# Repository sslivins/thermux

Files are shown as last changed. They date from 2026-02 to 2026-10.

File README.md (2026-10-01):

# Thermux

A multi-sensor temperature monitoring system for ESP32-POE boards with Home Assistant integration via MQTT auto-discovery. **Supports 20 DS18B20 sensors on a single 1-Wire bus by default, configurable up to 100** (`CONFIG_MAX_SENSORS`) - perfect for monitoring multiple zones, equipment, or environments from one device.

## Features

- **Up to 100 DS18B20 Sensors** - Monitor multiple temperature points from a single device on one 1-Wire bus (20 by default; raise `CONFIG_MAX_SENSORS` in menuconfig, max 100)
- **Optimized Parallel Reads** - Uses 1-Wire skip ROM command to read all sensors simultaneously (~1050ms for 20 sensors in 12-bit mode, ~450ms in 9-bit)
- **Home Assistant Integration** - MQTT auto-discovery for seamless integration
- **Modbus TCP** - Optional read-only Modbus TCP server so PLCs and heat pump controllers can read temperatures directly (see [Modbus TCP](#modbus-tcp))
- **BACnet/IP** - Optional read-only BACnet/IP server for building-automation systems (see [BACnet/IP](#bacnetip))
- **Web Interface** - Configuration and monitoring via built-in web server
- **Sensor Identification** - Change detection highlighting helps identify which physical sensor is which
- **Custom Sensor Names** - Assign friendly names to sensors via web UI (persisted in NVS)
- **OTA Updates** - Over-the-air firmware updates from GitHub releases or manual upload with progress display, including a native Home Assistant firmware **update entity** with an Install button and progress bar
- **Ethernet & WiFi** - Primary Ethernet with WiFi fallback
- **mDNS** - Access via `thermux.local` (auto-increments on collision: thermux-2.local, etc.)
- **Service Discovery** - Discoverable via `_thermux._tcp` and `_http._tcp` services
- **Web-based Logs** - View system logs without serial connection (16KB circular buffer)
- **Bus Error Tracking** - Monitor 1-Wire CRC error rates per sensor and globally via web UI and Home Assistant
- **Runtime Log Level Control** - Change log verbosity via web UI without reflashing
- **Session-based Authentication** - Optional password protection with login page
- **API Key Authentication** - Stateless API access for scripts and automation

## Hardware Requirements

- **Board**: [Olimex ESP32-POE-ISO](https://www.olimex.com/Products/IoT/ESP32/ESP32-POE-ISO/) (or compatible ESP32-POE board)
- **Sensors**: DS18B20 1-Wire temperature sensors
- **Connection**: Sensors connected to GPIO4 (configurable in menuconfig)
- **PCB** (optional): Custom breakout board - see [hardware/](hardware/) for KiCad files and BOM
- **Enclosure** (optional): 3D printable case - see [enclosure/](enclosure/) for print files

### Wiring

| DS18B20 Pin | ESP32-POE |
|---|---|
| VCC (Red) | 3.3V |
| GND (Black) | GND |
| DATA (Yellow) | GPIO4 |

> **Note**: A 4.7kΩ pull-up resistor is required between DATA and VCC. For 10+ sensors, use 2.2kΩ or 1.5kΩ to ensure reliable bus communication (the ESP32's internal pull-up is too weak for 1-Wire).

## Installation

### Pre-built Firmware (Recommended)

Download the latest firmware from [GitHub Releases](https://github.com/sslivins/thermux/releases/latest) and follow the [FLASHING.md](FLASHING.md) guide.

**For brand new ESP32-POE devices**, you'll need all three files:
- `bootloader.bin`
- `partition-table.bin`
- `thermux.bin`

**For OTA updates** on devices already running Thermux, use the web interface at `http://thermux.local/ota` - it downloads and installs updates automatically (no manual file download needed). You can also manually upload a specific `thermux.bin` version if desired.

See [FLASHING.md](FLASHING.md) for detailed instructions.

### Building from Source

#### Prerequisites

- [ESP-IDF v5.5.x](https://docs.espressif.com/projects/esp-idf/en/latest/esp32/get-started/)
- VS Code with ESP-IDF extension (recommended)

#### Build & Flash

```bash
# Set target
idf.py set-target esp32

# Build
idf.py build

# Flash
idf.py -p COMx flash monitor
```

Or use the ESP-IDF VS Code extension build/flash commands.

## Configuration

After flashing, access the web interface at `http://thermux.local` or the device IP.

> **Note**: If multiple devices are on the network, subsequent devices will be `thermux-2.local`, `thermux-3.local`, etc.

### Web Interface Pages

- **/** - Dashboard with live temperature readings
- **/config** - Configuration settings (MQTT, WiFi, sensor intervals, OTA)
- **/ota** - Manual firmware upload

### Configuration Options

| Setting | Description |
|---|---|
| **MQTT Broker** | Home Assistant MQTT broker address |
| **MQTT Port** | Broker port (default: 1883) |
| **MQTT Username/Password** | Authentication credentials |
| **WiFi SSID/Password** | Fallback WiFi credentials |
| **Read Interval** | Sensor polling interval (seconds) |
| **Publish Interval** | MQTT publish interval (seconds) |
| **OTA URL** | GitHub releases URL for automatic updates |
| **Security** | Enable/disable password protection |

## REST API

Full API documentation is available as an OpenAPI 3.1 spec: [`docs/openapi.yaml`](docs/openapi.yaml)

View it interactively: [Swagger Editor](https://editor.swagger.io/?url=https://raw.githubusercontent.com/sslivins/thermux/main/docs/openapi.yaml)

## Home Assistant Integration

The device automatically registers sensors with Home Assistant via MQTT discovery. Each sensor appears as a temperature entity. Diagnostics include network status, uptime, seconds since the last successful bus read, consecutive failed bus cycles, and a rolling error rate across the most recent 1,000 reads. Lifetime read counters remain available as disabled-by-default engineering diagnostics.

### Firmware Update Entity

Thermux publishes a native Home Assistant **`update` entity** (device class `firmware`) via MQTT discovery. It shows the installed version, the latest available GitHub release, a link to the release notes, and an **Install** button that triggers the OTA download **with a live progress bar** — the same experience as updating any other HA device, no automation or REST command needed.

The entity is backed by these MQTT topics (base topic configurable, default `thermux`):

| Topic | Direction | Purpose |
|---|---|---|
| `homeassistant/update/thermux_firmware/config` | retained | Discovery config |
| `thermux/update/state` | device → HA (retained) | JSON: `installed_version`, `latest_version`, `release_url`, `update_percentage`, `in_progress` |
| `thermux/update/install` | HA → device | Payload `install` starts the OTA |

The device checks GitHub for new releases periodically (see `OTA_CHECK_INTERVAL_HOURS`) and updates the entity whenever availability or download progress changes.

### Manual REST Integration (Optional)

You can also poll sensors directly:

```yaml
# configuration.yaml
rest:
  - resource: http://thermux.local/api/sensors
    scan_interval: 60
    sensor:
      - name: "Temperature Sensor 1"
        value_template: "{{ value_json[0].temperature }}"
        unit_of_measurement: "°C"
        device_class: temperature
```

## Modbus TCP

Thermux can run a small, **read-only** Modbus TCP server so a PLC or heat pump controller can read temperatures without HTTP or JSON. It's off by default: turn it on under **Settings → Modbus TCP**, where you can also set the port (default 502) and unit ID (default 1).

Modbus has no password. Anyone on the network can read the registers, but nothing can be changed over Modbus, so only enable it on a network you trust.

### Sensor channels

Each sensor gets a **channel** (0–99) the first time it's seen, keyed by its ROM ID. A sensor keeps its channel when other sensors are added or removed, so a register address (and BACnet object) always refers to the same physical sensor. New sensors fill the lowest free channels, in ROM ID order. Modbus TCP and BACnet/IP share the same channels: channel N is input register 100+N and BACnet Analog Input N.

The **Settings → Sensor Channels** section shows each channel's Modbus register, BACnet object, sensor, and the status and temperature clients are currently reading. From there you can:

- **Move** a sensor to another channel. If that channel is in use, the two sensors swap.
- **Release** the channel of a sensor that has been disconnected, so the channel can be reused. Channels of connected sensors can't be released; they would just be reassigned on the next read.

Channels and Modbus settings are included in backups (**Settings → Backup**), so a replacement Thermux can serve the same register map.

### Register map

All registers are **input registers**, read with function code 04. Addresses are zero-based. All 100 channels are always mapped, whatever `CONFIG_MAX_SENSORS` is set to, so the map never changes between builds.

| Address | Contents |
|---|---|
| 0 | Map version (currently 1) |
| 1–3 | Firmware version: major, minor, patch |
| 4 | Channel capacity (always 100) |
| 5 | Read-cycle counter. Goes up by one after every scheduled read attempt, including failed ones; wraps at 65535 |
| 6–7 | Uptime in seconds (32-bit, register 6 is the high word) |
| 8–10 | Ethernet MAC address, two bytes per register (register 8 = byte 0 << 8 \| byte 1) |
| 11 | Firmware sensor limit (`CONFIG_MAX_SENSORS`) |
| 12 | Number of channels in use |
| 13 | Number of sensors found on the bus |
| 14 | Result of the last read cycle: 0 OK, 1 some sensors failed, 2 bus failure, 3 no sensors |
| 15 | Read interval in seconds |
| 100 + channel | Temperature in hundredths of a °C, signed 16-bit (2150 = 21.50 °C, 0xFF38 = −2.00 °C). **0x8000 whenever the status isn't OK** |
| 200 + channel | Status (see below) |
| 300 + channel | Seconds since the last successful read (capped at 65534). 65535 if the sensor has never been read or isn't connected |
| 1000 + 4 × channel | ROM ID, 4 registers per channel, two bytes per register in the same order as the address shown in the UI and API |

Channel status, checked in this order:

| Value | Meaning |
|---|---|
| 1 | Unassigned: no sensor in this channel |
| 2 | Missing: the sensor wasn't found in the latest bus scan |
| 3 | Read error: the sensor's latest read failed, or the whole read cycle failed |
| 4 | Stale: never read successfully, or the last good reading is older than 3 × the read interval (at least 30 s) |
| 0 | OK |

Use the age registers if you need a stricter freshness limit than the stale rule.

Each block (0–15, 100–199, 200–299, 300–399, 1000–1399) is separate. A read that covers an address outside those blocks, or runs from one block into the next, returns exception 0x02 (illegal data address). A single read can cover at most 125 registers, so the ROM block takes four reads.

### Reading a consistent set

A reading cycle can finish between two of your requests. To be sure the values you read all come from the same cycle, read register 5, read the blocks you need, then read register 5 again. If it changed, read again.

### Unit ID and errors

- Address requests to the configured unit ID (default 1). Unit ID 0 is also answered.
- Requests for any other unit ID get exception 0x0B (gateway target device failed to respond).
- Unit ID 255 isn't answered: the Modbus library Thermux uses (esp-modbus 2.1.3) drops it before it reaches the server. A fix has been submitted upstream ([espressif/esp-modbus#190](https://github.com/espressif/esp-modbus/pull/190)).
- Every function code other than 04, including all writes, gets exception 0x01 (illegal function).
- Up to 3 clients can be connected at once.

### Discovery

While the server is running, Thermux advertises it over mDNS as `_mbap._tcp`, with TXT records `unit` (unit ID), `id` (MAC address) and `map` (map version). Most PLCs don't use mDNS, so you'll usually enter the IP address and port by hand; give Thermux a DHCP reservation so the address doesn't change.

### Examples

The repo includes a small reader, `scripts/thermux_modbus.py` (needs `pip install pymodbus`). With just an address it decodes the whole map; `channel` reads specific channels; `raw` reads any range from any Modbus TCP device:

```bash
python scripts/thermux_modbus.py thermux.local               # device info + every channel
python scripts/thermux_modbus.py thermux.local --watch 5     # repeat every 5 s
python scripts/thermux_modbus.py thermux.local channel 3     # one channel: temperature, status, age, ROM ID
python scripts/thermux_modbus.py thermux.local channel 3 7   # several channels
python scripts/thermux_modbus.py thermux.local channel 3 --value   # just the °C value, for scripts
python scripts/thermux_modbus.py 192.168.1.50 --port 502 --unit 1 raw 100 6          # input registers
python scripts/thermux_modbus.py 192.168.1.50 raw 0 10 --fc 3                        # holding registers
```

[mbpoll](https://github.com/epsilonrt/mbpoll), temperatures of channels 0–5 (`-0` makes addresses zero-based):

```bash
mbpoll -m tcp -a 1 -0 -t 3 -r 100 -c 6 -1 thermux.local
```

Python with [pymodbus](https://github.com/pymodbus-dev/pymodbus) 3.9 or later (older versions use `slave=` instead of `device_id=`):

```python
from pymodbus.client import ModbusTcpClient

client = ModbusTcpClient("thermux.local", port=502)
client.connect()

def read(address, count):
    result = client.read_input_registers(address, count=count, device_id=1)
    if result.isError():
        raise RuntimeError(result)
    return result.registers

while True:
    cycle = read(5, 1)[0]
    temps = read(100, 10)
    status = read(200, 10)
    if read(5, 1)[0] == cycle:
        break

for channel, (raw, st) in enumerate(zip(temps, status)):
    if st == 0:
        celsius = (raw - 65536 if raw >= 32768 else raw) / 100
        print(f"channel {channel}: {celsius:.2f} °C")
```

## BACnet/IP

Thermux can also run a **read-only** BACnet/IP server, for building-automation systems that speak BACnet rather than Modbus. It's off by default: turn it on under **Settings → BACnet/IP**. Modbus and BACnet can run at the same time and serve the same sensor channels.

| Setting | Default | Notes |
|---|---|---|
| UDP port | 47808 (0xBAC0) | The standard BACnet/IP port. Can't be the web server's port |
| Device instance | Derived from the Ethernet MAC | 0–4194302. Must be unique on the BACnet network, so set it by hand if your site has a numbering plan |
| Device name | The hostname | Up to 63 characters |

Like Modbus, BACnet has no password. Anyone on the network can read the objects, but nothing can be changed, so only enable it on a building-controls network you trust.

### Objects

The **Device** object reports vendor and model `Thermux`, the firmware version, and an object list.

Each assigned [sensor channel](#sensor-channels) is an **Analog Input**, and the instance number is the channel number. AI 3 is always channel 3, which is Modbus register 103. Unassigned channels have no object, so the object list only shows channels with a sensor.

| Property | Value |
|---|---|
| Object name | The sensor's friendly name, or `Channel N` if it has none. If two sensors have the same name, the second gets ` (N)` added, because BACnet object names must be unique |
| Description | The sensor's ROM ID, for example `281491BA00000069` |
| Present value | Temperature in °C. If a reading fails, the last good value stays and Reliability shows the fault |
| Units | degrees-Celsius |
| Reliability | `no-fault-detected` when OK; `no-sensor` when the sensor is missing; `communication-failure` on a read error; `unreliable-other` when the reading is stale |
| Status flags | `fault` is set whenever Reliability isn't `no-fault-detected` |
| COV increment | 0.1 °C |

When sensors are added, removed or renamed, the object list changes and the device's Database Revision goes up, so clients that cache the object list know to read it again.

### Services

- Who-Is / I-Am and Who-Has / I-Have
- ReadProperty and ReadPropertyMultiple
- SubscribeCOV (confirmed and unconfirmed), up to 16 subscriptions at once. Thermux sends a notification whenever a temperature changes by 0.1 °C or more, or its status flags change.

All write and management services (WriteProperty, CreateObject, ReinitializeDevice, DeviceCommunicationControl and so on) are rejected with `unrecognized-service`.

If the device's IP address changes (a new DHCP lease, for example), Thermux notices within a few seconds and sends a new I-Am. You don't need to restart anything.

### Example

The repo includes `scripts/thermux_bacnet.py`, which needs [BAC0](https://github.com/ChristianTremblay/BAC0) 2025 or later (`pip install BAC0`):

```bash
python scripts/thermux_bacnet.py --discover                       # Who-Is on the local network
python scripts/thermux_bacnet.py 192.168.1.50                     # device info and every Analog Input
python scripts/thermux_bacnet.py 192.168.1.50 --cov 60            # watch COV notifications for a minute
python scripts/thermux_bacnet.py 192.168.1.50 --try-write         # check that writes are rejected
python scripts/thermux_bacnet.py 192.168.1.50 --port 47809        # non-standard port
```

Add `--local 192.168.1.32/24` (your PC's address) if the script picks the wrong network interface. Who-Is discovery only finds devices on port 47808. On another port, I-Am replies are broadcast to that port, so give the address and `--port` instead.

## OTA Updates

Thermux can update three ways: the native Home Assistant **update entity** (above), the built-in **web interface**, or a **manual `.bin` upload**.

### Automatic Updates (Recommended)

The web interface can automatically download and install updates from GitHub releases:

1. Configure the OTA URL in web settings: `https://api.github.com/repos/sslivins/thermux/releases/latest`
2. Go to the OTA page and click "Check for Updates"
3. If a newer version is available, click "Update Now"
4. The device downloads, flashes, and reboots automatically - **no manual file download needed**

### Manual Upload

To install a **specific version** or **older version**, use the manual upload feature:

1. Download the desired `thermux.bin` from any [release](https://github.com/sslivins/thermux/releases)
2. Navigate to `/ota` page
3. Select the `.bin` firmware file
4. Click "Upload & Flash"

## Security

By default, the web interface is open (no authentication required). To enable password protection:

1. Go to `/config` → Security section
2. Check "Enable password protection"
3. Set username and password
4. Click "Save Security Settings"

When enabled, unauthorized access redirects to a login page. Sessions are stored in a cookie and expire after 7 days.

### API Key Authentication

For scripts and automation, use the API key instead of session cookies:

```bash
# Get sensor readings
curl -H "X-API-Key: YOUR_API_KEY" http://thermux.local/api/sensors

# Get device status
curl -H "X-API-Key: YOUR_API_KEY" http://thermux.local/api/status
```

The API key is:
- **Auto-generated** when authentication is first enabled
- **Visible** in Settings → Security section (click 📋 to copy)
- **Regeneratable** if compromised (click 🔄 to generate new key)
- **Persisted** across reboots in NVS flash

### Session Authentication

For browser-based access, the web UI uses session cookies. Protected API endpoints return `401 Unauthorized` with JSON body containing `{"login_required": true}` when not authenticated.

#### Auth Endpoints

| Endpoint | Method | Description |
|---|---|---|
| `/login` | GET | Login page (no auth required) |
| `/api/auth/login` | POST | Authenticate with `{"username":"...", "password":"..."}` |
| `/api/auth/logout` | POST | Destroy session |
| `/api/auth/status` | GET | Check if logged in |
| `/api/config/auth` | GET | Get auth config (includes API key) |
| `/api/config/auth/regenerate-key` | POST | Generate new API key |

### Home Assistant Integration

With API key authentication, REST integrations are straightforward:

```yaml
# configuration.yaml
rest:
  - resource: http://thermux.local/api/sensors
    headers:
      X-API-Key: "your-api-key-here"
    sensor:
      - name: "Pool Temperature"
        value_template: "{{ value_json.sensors[0].temperature }}"
        unit_of_measurement: "°C"
```

Alternatively, use the built-in MQTT integration with Home Assistant auto-discovery (no API key needed for MQTT).

## Technical Notes

### Optimized Temperature Reading

The firmware uses the 1-Wire **skip ROM** command (`0xCC`) to trigger temperature conversion on all DS18B20 sensors simultaneously, then reads each sensor individually. This reduces read time from O(n × delay) to O(delay + n × read):

| Sensors | Sequential (12-bit) | Parallel (12-bit) | Parallel (9-bit) |
|---|---|---|---|
| 1 | ~800ms | ~800ms | ~100ms |
| 5 | ~4000ms | ~850ms | ~150ms |
| 10 | ~8000ms | ~900ms | ~250ms |
| 20 | ~16000ms | ~1050ms | ~450ms |

The conversion delay depends on resolution: 12-bit = 750ms, 11-bit = 375ms, 10-bit = 188ms, 9-bit = 94ms. The parallel read overhead per sensor is minimal (~25ms for bus communication).

### Log Buffer

A 16KB circular buffer captures ESP-IDF logs for web display. Noisy system components (HTTP server internals, Ethernet MAC, etc.) are filtered to keep logs useful. The buffer can be viewed, cleared, and downloaded from the config page.

## Hardware Design

This repository includes open-source hardware designs:

### PCB ([hardware/](hardware/))

Two open-source KiCad boards:

- **Sensor Bus Hat** - plugs onto the ESP32-POE-ISO and breaks the 1-Wire bus out to RJ45 (carries the bus pull-up resistor)
- **Temperature Node** - DS18B20 breakout with RJ45 connectors for daisy-chaining sensors

- **KiCad project files** - Full schematic and PCB layout
- **Gerber files** - Ready for fabrication (JLCPCB, PCBWay, etc.)
- **Bill of Materials** - DigiKey part links

### Enclosure ([enclosure/](enclosure/))

3D printable cases, in two parts:

- **ESP32-POE-ISO Case** - the main enclosure; houses the ESP32-POE-ISO with the Sensor Bus Hat plugged on
- **Temperature Node** - two-part case (PCB + enclosure) for a distributed DS18B20 sensor node on the 1-Wire bus

Each is provided as:

- **Fusion 360** (.f3d / .f3z) - Parametric source files
- **STEP** (.step) - Universal CAD interchange format
- **Print files** (.3mf, .stl) - Ready for slicing

## Version History

See [GitHub Releases](https://github.com/sslivins/thermux/releases) for changelog.

## License

MIT License - See [LICENSE](LICENSE) for details.

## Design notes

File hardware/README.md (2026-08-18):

# Hardware

Open-source PCB design files for Thermux. There are **two** boards:

- **Sensor Bus Hat** ([`sensor_bus_hat/`](sensor_bus_hat/)) — plugs onto the
  Olimex ESP32-POE-ISO and breaks the 1-Wire bus out to an RJ45 jack, carrying
  the bus pull-up resistor.
- **Temperature Node** ([`temp_node/`](temp_node/)) — the distributed DS18B20
  sensor breakout with RJ45 connectors for daisy-chaining sensors along the bus.

## Directory Structure

```
hardware/
├── sensor_bus_hat/     # ESP32-POE-ISO bus-adapter hat
│   ├── kicad/          # KiCad project (.kicad_pro, .kicad_sch, .kicad_pcb)
│   └── gerbers/        # Manufacturing files (gerbers, drills, BOM, CPL)
├── temp_node/          # DS18B20 sensor breakout node
│   ├── kicad/
│   └── gerbers/
└── README.md
```

Each board's `gerbers/` folder is self-contained — zip its contents (or upload
the folder) to JLCPCB / PCBWay to fabricate that board.

## Sensor Bus Hat

Adapter board that sits on the Olimex ESP32-POE-ISO and exposes the 1-Wire bus
on an RJ45 jack. It carries the bus **pull-up resistor** (see the pull-up note
below).

### Bill of Materials

| Qty | Designator | Description | Part Number |
|-----|---|---|---|
| 1 | R1 | Pull-up resistor, 4.7 kΩ (0805) — see pull-up note | (generic) |
| 1 | J1 | RJ45 Connector | GCT MJ3225-88-0 |
| 1 | J2 | 10-pin 2.54 mm pin socket (to ESP32-POE-ISO) | (generic) |

> **Pull-up note:** R1 is populated as **4.7 kΩ**, which is correct for a small
> bus. For **10+ sensors** on a long bus, drop to **2.2 kΩ or 1.5 kΩ** (a
> *lower* resistance = stronger pull-up) for reliable 1-Wire communication — the
> ESP32's internal pull-up alone is too weak.

## Temperature Node

Custom breakout board with RJ45 connectors for daisy-chaining DS18B20 sensors.

### PCB Features

- DS18B20 sensor breakout
- Screw terminal connections
- Compatible with Olimex ESP32-POE-ISO

### Bill of Materials

| Qty | Description | Part Number | DigiKey Link |
|-----|---|---|---|
| 2 | RJ45 Connector | GCT MJ3225-88-0 | [MJ3225-88-0](https://www.digikey.com/en/products/detail/gct/MJ3225-88-0/16893750) |
| 1 | JST XH Header (3-pin) | JST S3B-XH-A | [S3B-XH-A](https://www.digikey.com/en/products/detail/jst-sales-america-inc/S3B-XH-A/1651048) |
| 1 | PTC Resettable Fuse | Murata PRG21AR420MS1RA | [PRG21AR420MS1RA](https://www.digikey.com/en/products/detail/murata-electronics/PRG21AR420MS1RA/2595394) |
| 1 | 10µF Capacitor (0805) | Samsung CL21B106KOQNNNE | [CL21B106KOQNNNE](https://www.digikey.com/en/products/detail/samsung-electro-mechanics/CL21B106KOQNNNE/3888530) |
| 1 | 0.1µF Capacitor (0805) | Samsung CL21B104KBCNNNC | [CL21B104KBCNNNC](https://www.digikey.com/en/products/detail/samsung-electro-mechanics/CL21B104KBCNNNC/3886661) |

## Manufacturing

Gerber files are ready for fabrication at JLCPCB, PCBWay, or similar services.

## License

Hardware designs are released under [CERN-OHL-P v2](https://ohwr.org/cern_ohl_p_v2.txt) (Permissive).

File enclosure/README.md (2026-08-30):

# Enclosure

3D printable enclosure designs for the Thermux temperature monitor.

There are two separate enclosures:

- **ESP32-POE-ISO Case** - the main enclosure. Houses the Olimex ESP32-POE-ISO with the **Sensor Bus Hat** plugged onto it (the Sensor Bus Hat has no enclosure of its own).
- **Temperature Node** - a two-part design (PCB + case) that houses a distributed DS18B20 sensor node along the 1-Wire bus.

## Directory Structure

```
enclosure/
├── fusion360/      # Autodesk Fusion 360 source files (.f3d / .f3z)
├── step/           # Universal CAD interchange format (.step)
├── print/          # Print-ready files (.3mf, .stl)
└── README.md
```

## Files

### ESP32-POE-ISO Case (main enclosure)

Houses the Olimex ESP32-POE-ISO with the Sensor Bus Hat plugged onto it.

- `fusion360/Thermux ESP32-POE-ISO Case.f3z` - Fusion 360 source (archive)
- `step/Thermux ESP32-POE-ISO Case.step` - STEP
- `print/ESP32-POE-ISO Case - Base.3mf` - print-ready base
- `print/ESP32-POE-ISO Case - Lid.3mf` - print-ready lid
- `print/ESP32-POE-ISO Case - Lid - Bambu.3mf` - print-ready lid pre-configured for Bambu Studio / Bambu Lab printers

### Temperature Node (DS18B20 sensor node)

- `fusion360/Thermux Temperature Node.f3d` - Fusion 360 source
- `step/Thermux Temperature Node.step` - STEP
- `print/Base.3mf` - print-ready base
- `print/Lid.3mf` - print-ready lid

## File Formats

- **Fusion 360 (.f3d / .f3z)** - Full design history for parametric editing (requires Fusion 360). `.f3z` is a Fusion archive export.
- **STEP (.step)** - Universal CAD format for other software (FreeCAD, SolidWorks, OnShape, etc.)
- **3MF (.3mf)** - Modern print format with colors/materials/settings (preferred)
- **STL (.stl)** - Legacy mesh format for older slicers

## Printing Recommendations

- **Material**: PETG or ASA for outdoor/moisture resistance
- **Layer Height**: 0.2mm
- **Infill**: 20-30%
- **Supports**: As needed

## Assembly Hardware

Fasteners are not 3D-printed and must be sourced separately.

### ESP32-POE-ISO Case (main enclosure)

| Qty | Part | Notes |
|-----|---|---|
| 4 | M3 × 4mm brass heat-set inserts | Press into the case bosses (one per corner) with a soldering iron |
| 4 | M3 × 6mm hex-head bolts | Fasten the lid to the case, one per corner |

### Temperature Node

Friction fit — **no fasteners required**. The lid press-fits onto the base.

## License

Enclosure designs are released under [CC BY-SA 4.0](https://creativecommons.org/licenses/by-sa/4.0/).

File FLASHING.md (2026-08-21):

# Flashing Thermux Firmware

This guide explains how to flash the Thermux firmware to your ESP32-POE device.

## Overview

- **Initial Flash** (brand new device): Requires all three binary files (bootloader, partition table, and application)
- **OTA Updates** (existing installation): Only requires the `thermux.bin` file via web interface

## Initial Flash (Brand New Device)

When flashing a brand new ESP32-POE device that has never had Thermux installed, you need to flash three binary files to specific memory locations.

### Required Files

Download all three files from the [latest release](https://github.com/sslivins/thermux/releases/latest):

1. `bootloader.bin` - ESP32 bootloader (flashed at 0x1000)
2. `partition-table.bin` - Partition layout (flashed at 0x8000)
3. `thermux.bin` - Main application (flashed at 0x20000)

### Prerequisites

#### Install esptool.py

```bash
pip install esptool
```

Or use the version that comes with ESP-IDF if you have it installed.

#### Identify Your Serial Port

**Linux:**
```bash
ls /dev/ttyUSB*
# Usually /dev/ttyUSB0
```

**macOS:**
```bash
ls /dev/cu.usbserial-*
# e.g., /dev/cu.usbserial-0001
```

**Windows:**
- Check Device Manager → Ports (COM & LPT)
- Usually COM3, COM4, etc.

### Flashing Commands

#### Linux / macOS

```bash
esptool.py --chip esp32 --port /dev/ttyUSB0 --baud 460800 write_flash \
  0x1000 bootloader.bin \
  0x8000 partition-table.bin \
  0x20000 thermux.bin
```

Replace `/dev/ttyUSB0` with your actual port.

#### Windows

```bash
esptool.py --chip esp32 --port COM3 --baud 460800 write_flash ^
  0x1000 bootloader.bin ^
  0x8000 partition-table.bin ^
  0x20000 thermux.bin
```

Replace `COM3` with your actual port.

#### Using ESP-IDF

If you have ESP-IDF installed, you can also use:

```bash
idf.py -p /dev/ttyUSB0 flash
```

However, this requires the full source code and build environment.

### Verification

After flashing:

1. Open serial monitor to see boot logs:
   ```bash
   esptool.py --port /dev/ttyUSB0 monitor
   # Or
   idf.py -p /dev/ttyUSB0 monitor
   ```

2. Connect to the device:
   - Via Ethernet: Check your router's DHCP table or try `http://thermux.local`
   - Via serial console: Watch for the IP address in boot logs

3. Access the web interface at `http://thermux.local` (or the IP address shown)

## OTA Updates (Existing Installation)

Once Thermux is already running on your device, you can update easily through the web interface. **No manual file downloads are needed** for automatic updates - the web interface handles everything for you.

### Option 1: Automatic Updates (Recommended)

The easiest way to update is to let the web interface download and install updates automatically from GitHub releases.

1. Go to `http://thermux.local/config`
2. In the OTA section, set the **OTA URL** to:
   ```
   https://api.github.com/repos/sslivins/thermux/releases/latest
   ```
3. Click "Save Configuration"
4. Go to `http://thermux.local/ota`
5. Click "Check for Updates"
6. If a newer version is available, click "Update Now"
7. **The device downloads the firmware automatically**, flashes it, and reboots - you don't need to download `thermux.bin` yourself

> **Note**: This is the recommended method for most users. The web interface downloads the latest `thermux.bin` from GitHub releases automatically.

### Option 2: Manual File Upload

Use this option if you want to install a **specific version** or **older version** of the firmware.

1. Download the desired `thermux.bin` from any [release](https://github.com/sslivins/thermux/releases)
2. Navigate to `http://thermux.local/ota`
3. Click "Choose File" and select the `thermux.bin` file you downloaded
4. Click "Upload & Flash"
5. Wait for the upload and flash to complete (~30 seconds)
6. The device will automatically reboot with the selected firmware

> **Use case**: Installing a specific version (e.g., rolling back to an older version or testing a pre-release)

### Option 3: Via Home Assistant

You can trigger OTA updates from Home Assistant using a REST command:

```yaml
# configuration.yaml
rest_command:
  update_thermux:
    url: "http://thermux.local/api/ota/update"
    method: POST
```

Then create an automation or script to call `rest_command.update_thermux`.

## Troubleshooting

### Flash Fails with "Failed to connect"

1. **Check USB cable**: Use a data cable, not a charge-only cable
2. **Hold BOOT button**: Some ESP32 boards require holding BOOT while connecting
3. **Try lower baud rate**: Use `--baud 115200` instead of 460800
4. **Check drivers**: Install CH340/CP2102 USB-to-serial drivers if needed

### Device Doesn't Boot After Flash

1. **Verify all three files were flashed** at the correct addresses
2. **Check file versions match**: All three files should be from the same release
3. **Try erasing flash first**:
   ```bash
   esptool.py --chip esp32 --port /dev/ttyUSB0 erase_flash
   ```
   Then flash again

### Can't Access Web Interface

1. **Check Ethernet connection**: Ensure cable is connected and link lights are on
2. **Check serial console**: Look for IP address in boot logs
3. **Try IP address directly**: If mDNS isn't working, use the IP from serial console
4. **Check router**: Look for "thermux" in DHCP client list
5. **Multiple devices**: If you have multiple Thermux devices, they'll be numbered (thermux-2.local, thermux-3.local, etc.)

### OTA Update Fails

1. **Check available flash space**: Monitor logs during update
2. **Verify network connection**: Ensure stable WiFi/Ethernet
3. **Check file size**: thermux.bin should be ~900KB - 1.2MB
4. **Try manual upload**: Use the web interface upload method instead of automatic
5. **Check logs**: View logs at `http://thermux.local/config` → Log Viewer section

## Advanced: Building from Source

If you want to build and flash from source code:

### Prerequisites

- [ESP-IDF v5.5.x](https://docs.espressif.com/projects/esp-idf/en/latest/esp32/get-started/)
- Git (for cloning repository)

### Build & Flash

```bash
# Clone repository
git clone https://github.com/sslivins/thermux.git
cd thermux

# Set ESP32 target
idf.py set-target esp32

# Build firmware
idf.py build

# Flash all partitions and monitor
idf.py -p /dev/ttyUSB0 flash monitor
```

The `idf.py flash` command automatically flashes all required partitions (bootloader, partition table, and application) to the correct addresses.

### Just Build (No Flash)

```bash
idf.py build
```

Binary files will be in `build/`:
- `build/bootloader/bootloader.bin`
- `build/partition_table/partition-table.bin`
- `build/thermux.bin`

## Flash Memory Layout

The Thermux firmware uses the following partition layout (as of v2.10.13 and later):

| Partition | Type | Address | Size | Purpose |
|---|---|---|---|---|
| Bootloader | - | 0x1000 | ~28KB | ESP32 second-stage bootloader |
| Partition Table | - | 0x8000 | ~3KB | Partition layout definition |
| NVS | data | 0x9000 | 24KB | Configuration storage (WiFi, MQTT, etc.) |
| OTA Data | data | 0xf000 | 8KB | OTA update state |
| phy_init | data | 0x11000 | 4KB | WiFi PHY calibration data |
| OTA_0 | app | 0x20000 | 1.875MB | OTA update slot 0 |
| OTA_1 | app | 0x200000 | 1.875MB | OTA update slot 1 |
| Storage | data | 0x3F0000 | 64KB | Additional NVS storage |

A brand-new device has no factory partition; the bootloader defaults to booting `OTA_0` when `otadata` is blank (all-0xFF), so an initial flash of `thermux.bin` at `0x20000` boots normally on first power-up. Once OTA updates begin, the device boots from whichever of `OTA_0`/`OTA_1` has the newest firmware.

### Partition layout history

Prior to v2.10.13, the layout used a separate `factory` partition (0x20000, 1.4MB) plus two smaller 1.2MB OTA slots (`OTA_0` at 0x190000, `OTA_1` at 0x2C0000). The `factory` slot was only ever used for the initial flash and was permanently wasted space afterward (a device never boots back into `factory` once an OTA update lands in `OTA_0`/`OTA_1`).

Existing field devices flashed before this change were migrated to the new layout entirely over-the-air (no reflash required), reclaiming the dead `factory` space and growing both OTA slots to 1.875MB each. See [issue #48](https://github.com/sslivins/thermux/issues/48) for the full migration design and validation history. This was a one-time, in-place migration; it does not need to be repeated and does not apply to devices already running v2.10.13+.

## Security Notes

- **Flash encryption**: Not enabled by default. Can be configured via `idf.py menuconfig`
- **Secure boot**: Not enabled by default. Can be configured via `idf.py menuconfig`
- **API authentication**: Disabled by default. Enable in web interface → Settings → Security

For production deployments requiring flash encryption or secure boot, refer to the [ESP-IDF Security Guide](https://docs.espressif.com/projects/esp-idf/en/latest/esp32/security/index.html).

## Support

- **GitHub Issues**: [https://github.com/sslivins/thermux/issues](https://github.com/sslivins/thermux/issues)
- **Discussions**: [https://github.com/sslivins/thermux/discussions](https://github.com/sslivins/thermux/discussions)
- **Documentation**: See [README.md](README.md) for feature documentation

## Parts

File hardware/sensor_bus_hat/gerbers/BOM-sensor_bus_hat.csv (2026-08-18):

Comment | Designator | Footprint | LCSC | Quantity
4.7k | R1 | R_0805_2012Metric |  | 1
Conn_01x10_Pin | J2 | PinSocket_1x10_P2.54mm_Vertical |  | 1
BUS | J1 | GCT_MJ3225-88-0_REVA |  | 1

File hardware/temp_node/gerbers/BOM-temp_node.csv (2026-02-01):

Comment | Designator | Footprint | LCSC | Quantity
TEMP_BUS_A | J1 | GCT_MJ3225-88-0_REVA |  | 1
TEMP_SENSOR | J2 | JST_XH_S3B-XH-A_1x03_P2.50mm_Horizontal |  | 1
PTC 54mA/100mA (resettable) | F1 | Fuse_0805_2012Metric |  | 1
TEMP_BUS_B | J3 | GCT_MJ3225-88-0_REVA |  | 1
0.1uF | C2 | C_0805_2012Metric |  | 1
10uF | C1 | C_0805_2012Metric |  | 1

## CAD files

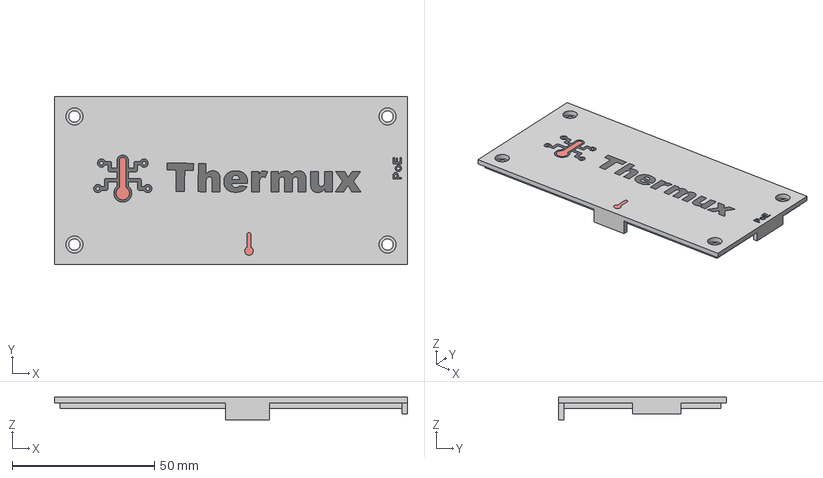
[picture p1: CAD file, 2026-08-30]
enclosure/print/ESP32-POE-ISO Case - Lid.3mf
124.0 x 59.0 x 8.00 mm
Lid
Logo - E
Logo - H
Logo - M
Logo - Probes
Logo - R
Logo - T
Logo - Thermometer
Logo - U
Logo - X
PoE - E
PoE - P
PoE - o
RJ45 - Thermometer

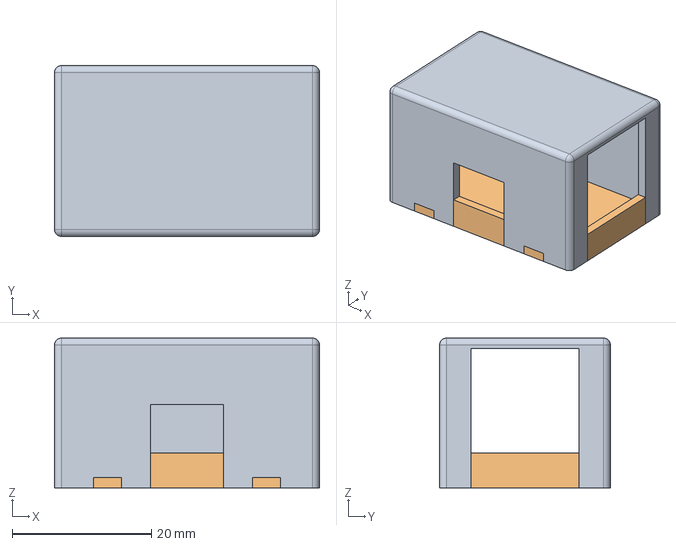
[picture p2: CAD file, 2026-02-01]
enclosure/step/Thermux Temperature Node.step
38.0 x 24.5 x 21.5 mm
Lid
Base

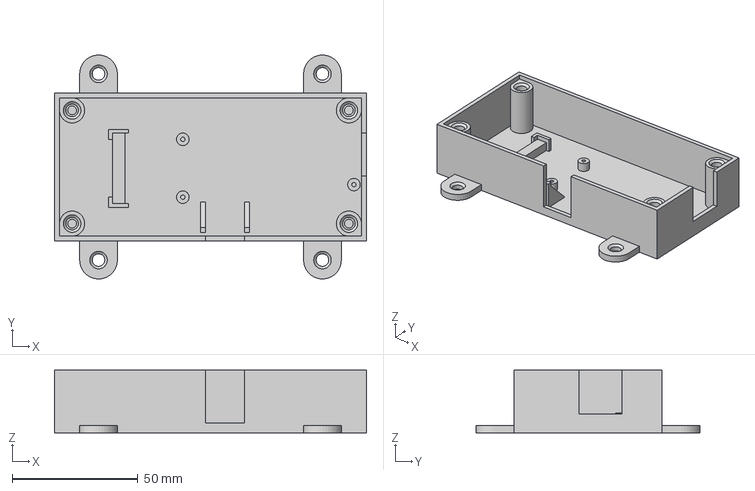
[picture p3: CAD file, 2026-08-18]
enclosure/print/ESP32-POE-ISO Case - Base.3mf
124.0 x 89.0 x 25.0 mm

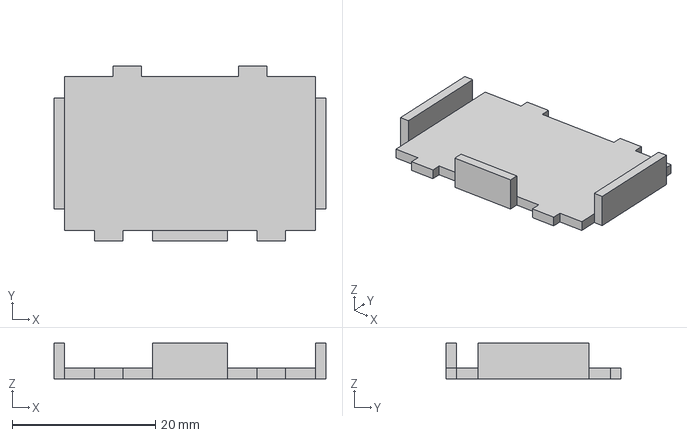
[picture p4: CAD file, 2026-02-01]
enclosure/print/Base.3mf
38.0 x 24.5 x 5.00 mm

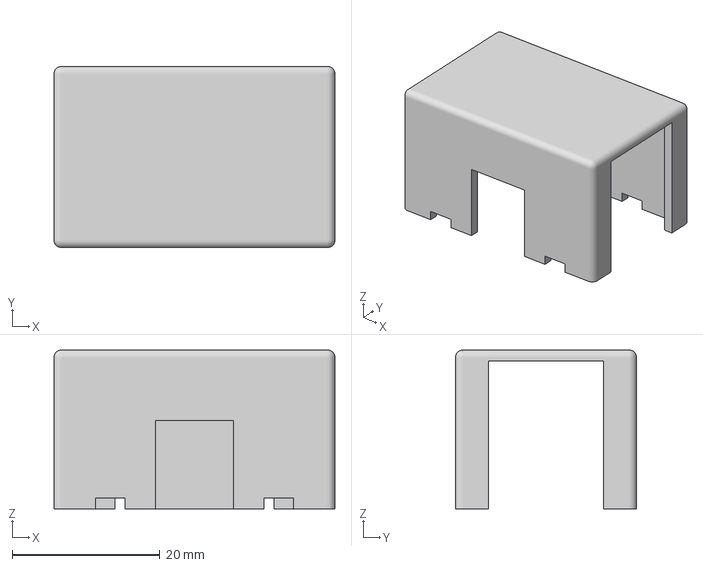
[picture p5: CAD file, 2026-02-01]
enclosure/print/Lid.3mf
38.0 x 24.5 x 21.5 mm

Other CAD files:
enclosure/step/Thermux ESP32-POE-ISO Case.step
enclosure/print/ESP32-POE-ISO Case - Lid - Bambu.3mf
enclosure/fusion360/Thermux ESP32-POE-ISO Case.f3z
enclosure/fusion360/Thermux Temperature Node.f3d

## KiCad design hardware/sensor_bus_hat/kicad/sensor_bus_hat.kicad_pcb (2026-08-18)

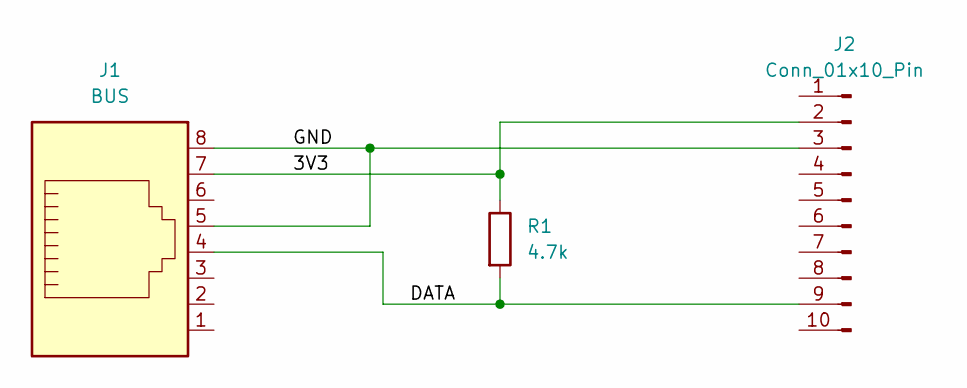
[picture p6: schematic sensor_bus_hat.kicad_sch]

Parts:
J1: BUS; GCT_MJ3225-88-0_REVA
J2: Conn_01x10_Pin; PinSocket_1x10_P2.54mm_Vertical
R1: 4.7k; R_0805_2012Metric

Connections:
/3V3: J1.7, J2.2, R1.1
/DATA: J1.4, J2.9, R1.2
/GND: J1.5, J1.8, J2.3

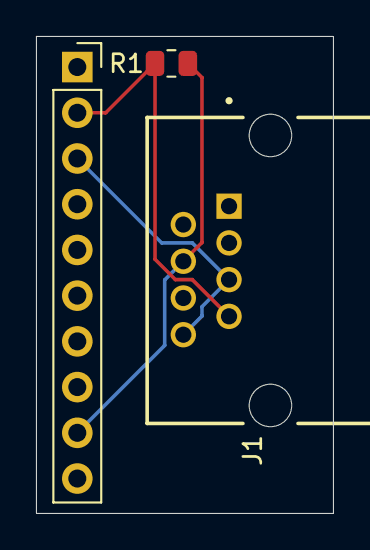
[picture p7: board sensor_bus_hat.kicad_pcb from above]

Board: 2 copper layers, 16.5 x 26.5 mm, 3 parts (0 on the bottom side), 3 nets.

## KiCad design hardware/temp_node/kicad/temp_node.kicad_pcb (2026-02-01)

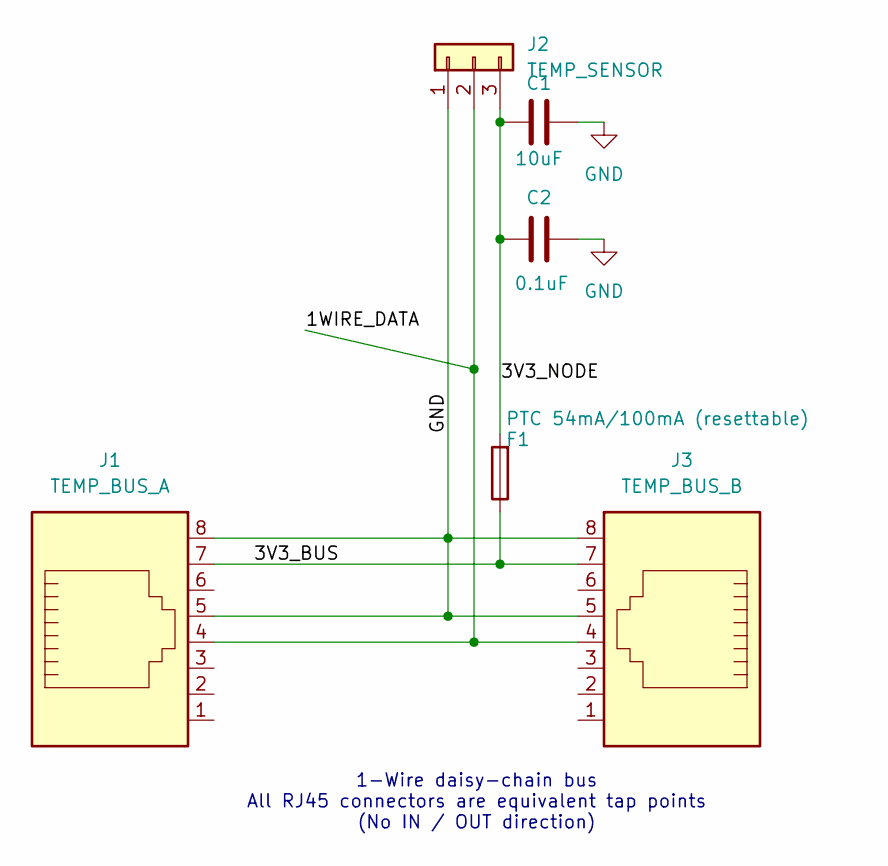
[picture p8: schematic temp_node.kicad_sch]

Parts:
C1: 10uF; C_0805_2012Metric
C2: 0.1uF; C_0805_2012Metric
F1: PTC 54mA/100mA (resettable); Fuse_0805_2012Metric
J1: TEMP_BUS_A; GCT_MJ3225-88-0_REVA
J2: TEMP_SENSOR; JST_XH_S3B-XH-A_1x03_P2.50mm_Horizontal
J3: TEMP_BUS_B; GCT_MJ3225-88-0_REVA

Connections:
/1WIRE_DATA: J1.4, J2.2, J3.4
/3V3_BUS: F1.1, J1.7, J3.7
/3V3_NODE: C1.2, C2.2, F1.2, J2.3
GND: C1.1, C2.1, J1.5, J1.8, J2.1, J3.5, J3.8

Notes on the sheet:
1-Wire daisy-chain bus All RJ45 connectors are equivalent tap points (No IN / OUT direction)

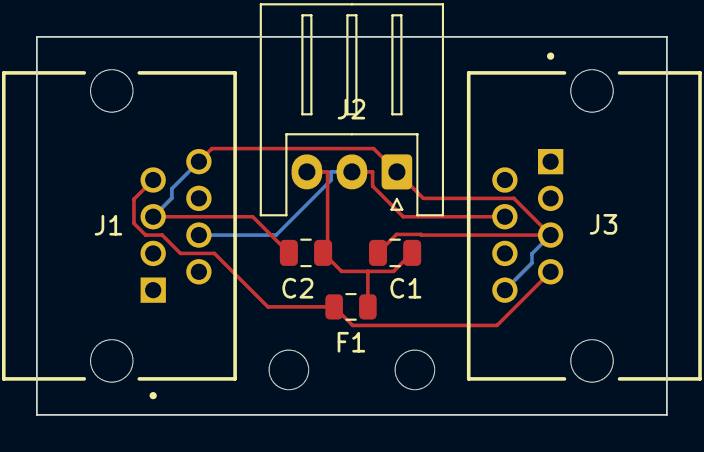
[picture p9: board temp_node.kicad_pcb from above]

Board: 2 copper layers, 35.0 x 21.0 mm, 8 parts (0 on the bottom side), 4 nets.

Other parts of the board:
H0, H1: MountingHole_2.2mm_M2

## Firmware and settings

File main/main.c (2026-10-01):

/**
 * @file main.c
 * @brief Thermux - Multi-Sensor Temperature Monitoring System
 * 
 * This application reads multiple DS18B20 1-Wire temperature sensors,
 * publishes readings to Home Assistant via MQTT, and provides a web
 * interface for sensor management.
 */

#include <stdio.h>
#include <string.h>
#include "freertos/FreeRTOS.h"
#include "freertos/task.h"
#include "freertos/event_groups.h"
#include "esp_system.h"
#include "esp_log.h"
#include "esp_event.h"
#include "nvs_flash.h"
#include "esp_netif.h"
#include "esp_ota_ops.h"
#include "mdns.h"

#include "nvs_storage.h"
#include "ethernet_manager.h"
#include "wifi_manager.h"
#include "onewire_temp.h"
#include "sensor_manager.h"
#include "modbus_server.h"
#include "bacnet_server.h"
#include "mqtt_client_ha.h"
#include "web_server.h"
#include "ota_updater.h"
#include "log_buffer.h"
#include "log_persist.h"
#include "time_sync.h"

static const char *TAG = "main";

/* Event group for network connectivity */
EventGroupHandle_t network_event_group;
const int NETWORK_CONNECTED_BIT = BIT0;

/* Application version - update for each release */
const char *APP_VERSION = "3.5.2";

/* Runtime sensor settings (can be changed via web UI) */
static uint32_t s_read_interval_ms = CONFIG_SENSOR_READ_INTERVAL_MS;
static uint32_t s_publish_interval_ms = CONFIG_SENSOR_PUBLISH_INTERVAL_MS;

/* Accessor functions for sensor settings */
uint32_t get_sensor_read_interval(void) { return s_read_interval_ms; }
uint32_t get_sensor_publish_interval(void) { return s_publish_interval_ms; }

void set_sensor_read_interval(uint32_t ms) { 
    s_read_interval_ms = ms; 
    ESP_LOGD(TAG, "Read interval set to %lu ms", ms);
}

void set_sensor_publish_interval(uint32_t ms) { 
    s_publish_interval_ms = ms; 
    ESP_LOGD(TAG, "Publish interval set to %lu ms", ms);
}

/**
 * @brief Initialize mDNS service for device discovery
 * 
 * Uses simple hostname with automatic collision handling (thermux.local, 
 * thermux-2.local, etc.). Registers discoverable services for network scanning.
 */
static esp_err_t init_mdns(void)
{
    esp_err_t err = mdns_init();
    if (err != ESP_OK) {
        ESP_LOGE(TAG, "mDNS init failed: %s", esp_err_to_name(err));
        return err;
    }

    /* Use simple hostname - mDNS handles collisions automatically */
    const char *hostname = CONFIG_MDNS_HOSTNAME;
    
    mdns_hostname_set(hostname);
    mdns_instance_name_set("Thermux Temperature Monitor");
    
    /* TXT records for service discovery */
    mdns_txt_item_t http_txt[] = {
        {"version", APP_VERSION},
        {"type", "temperature"},
    };
    
    /* Add HTTP service for web interface discovery */
    mdns_service_add("Thermux", "_http", "_tcp", CONFIG_WEB_SERVER_PORT, http_txt, 2);
    
    /* Add custom service type for easy discovery of all Thermux devices */
    mdns_service_add("Thermux", "_thermux", "_tcp", CONFIG_WEB_SERVER_PORT, http_txt, 2);
    
    ESP_LOGD(TAG, "mDNS hostname: %s.local", hostname);
    ESP_LOGD(TAG, "mDNS services: _http._tcp, _thermux._tcp");
    return ESP_OK;
}

/**
 * @brief Confirm the running firmware healthy, or roll back after a bad OTA
 *
 * With bootloader app-rollback enabled, a freshly flashed image boots in the
 * PENDING_VERIFY state. We confirm it (so the bootloader keeps it) once the
 * device proves healthy - here, the network came up. If the health check
 * failed we invalidate the image and reboot into the previous known-good slot.
 * On a normal boot (image already marked valid) this is a no-op, so it is safe
 * to call unconditionally.
 *
 * @param healthy true if the post-boot health check passed (network is up)
 */
static void ota_confirm_or_rollback(bool healthy)
{
#if CONFIG_BOOTLOADER_APP_ROLLBACK_ENABLE
    const esp_partition_t *running = esp_ota_get_running_partition();
    esp_ota_img_states_t state;
    if (running == NULL || esp_ota_get_state_partition(running, &state) != ESP_OK) {
        return;
    }
    if (state != ESP_OTA_IMG_PENDING_VERIFY) {
        return; /* already valid (or factory) - nothing to verify */
    }

    if (healthy) {
        esp_err_t err = esp_ota_mark_app_valid_cancel_rollback();
        if (err == ESP_OK) {
            ESP_LOGI(TAG, "New firmware verified healthy; rollback cancelled");
        } else {
            ESP_LOGE(TAG, "mark_app_valid failed: %s", esp_err_to_name(err));
        }
    } else {
        ESP_LOGE(TAG, "New firmware failed health check; rolling back to previous slot");
        esp_ota_mark_app_invalid_rollback_and_reboot(); /* reboots; does not return */
        ESP_LOGE(TAG, "Rollback not possible (no previous slot); staying on current image");
    }
#else
    (void)healthy;
#endif
}

/**
 * @brief Network event handler
 */
static void network_event_handler(void *arg, esp_event_base_t event_base,
                                  int32_t event_id, void *event_data)
{
    if (event_base == IP_EVENT && event_id == IP_EVENT_ETH_GOT_IP) {
        ip_event_got_ip_t *event = (ip_event_got_ip_t *)event_data;
        ESP_LOGI(TAG, "Ethernet got IP: " IPSTR, IP2STR(&event->ip_info.ip));
        xEventGroupSetBits(network_event_group, NETWORK_CONNECTED_BIT);
    } else if (event_base == IP_EVENT && event_id == IP_EVENT_STA_GOT_IP) {
        ip_event_got_ip_t *event = (ip_event_got_ip_t *)event_data;
        ESP_LOGI(TAG, "WiFi got IP: " IPSTR, IP2STR(&event->ip_info.ip));
        xEventGroupSetBits(network_event_group, NETWORK_CONNECTED_BIT);
    }
}

/**
 * @brief Temperature reading task
 */
static void temperature_task(void *pvParameters)
{
    ESP_LOGD(TAG, "Temperature task started");
    
    while (1) {
        /* Read all connected sensors */
        sensor_manager_read_all();
        modbus_server_update();
        bacnet_server_update();
        
        vTaskDelay(pdMS_TO_TICKS(s_read_interval_ms));
    }
}

/**
 * @brief MQTT publishing task
 */
static void mqtt_publish_task(void *pvParameters)
{
    ESP_LOGD(TAG, "MQTT publish task started");
    
    /* Wait for MQTT to connect */
    vTaskDelay(pdMS_TO_TICKS(5000));
    
    while (1) {
        if (mqtt_ha_is_connected()) {
            sensor_manager_publish_all();
        }
        
        vTaskDelay(pdMS_TO_TICKS(s_publish_interval_ms));
    }
}

/**
 * @brief OTA check task
 */
static void ota_check_task(void *pvParameters)
{
    ESP_LOGD(TAG, "OTA check task started");
    
    /* Initial delay before first check */
    vTaskDelay(pdMS_TO_TICKS(60000));
    
    while (1) {
#if CONFIG_OTA_ENABLED
        ota_check_for_update();
#endif
        /* Check at configured interval. pdMS_TO_TICKS() multiplies the
         * millisecond value by configTICK_RATE_HZ before dividing by 1000,
         * so passing a full 24h-in-ms value (86,400,000) overflows 32 bits
         * and wraps to a ~8-minute delay instead - which was silently
         * causing the OTA check (and its "update available" MQTT publish)
         * to re-run every ~8 minutes rather than once a day. Delay in
         * seconds and use pdSECOND_TO_TICKS-equivalent math to stay well
         * clear of the overflow. */
        uint32_t interval_s = (uint32_t)CONFIG_OTA_CHECK_INTERVAL_HOURS * 3600;
        vTaskDelay(pdMS_TO_TICKS(1000) * interval_s);
    }
}

#if CONFIG_OTA_ENABLED
/**
 * @brief Mirror OTA state to the Home Assistant "update" entity
 *
 * Publishes installed/latest version and live download progress to MQTT
 * whenever it changes, so HA's update card shows availability and a progress
 * bar. Polls fast while an install is running, slow otherwise.
 */
static void ota_status_publish_task(void *pvParameters)
{
    char last_latest[32] = {0};
    int last_pct = -2;            /* sentinel: force the first publish */
    bool last_connected = false;

    while (1) {
        bool connected = mqtt_ha_is_connected();

        if (connected) {
            char latest[32] = {0};
            if (ota_is_update_available()) {
                ota_get_latest_version(latest, sizeof(latest));
            } else {
                strncpy(latest, APP_VERSION, sizeof(latest) - 1);
            }

            int st = ota_get_update_state();   /* 0 idle, 1 downloading, 2 complete, -1 failed */
            int pct = (st == 1) ? ota_get_download_progress() : -1;

            bool reconnected = connected && !last_connected;
            if (reconnected || pct != last_pct ||
                strncmp(latest, last_latest, sizeof(latest)) != 0) {

                const char *release_url = NULL;
                char url_buf[128];
                if (ota_is_update_available()) {
                    snprintf(url_buf, sizeof(url_buf),
                             "https://github.com/%s/%s/releases/latest",
                             CONFIG_GITHUB_OWNER, CONFIG_GITHUB_REPO);
                    release_url = url_buf;
                }

                mqtt_ha_publish_update_state(APP_VERSION, latest, release_url, pct);

                strncpy(last_latest, latest, sizeof(last_latest) - 1);
                last_latest[sizeof(last_latest) - 1] = '\0';
                last_pct = pct;
            }
        }
        last_connected = connected;

        vTaskDelay(pdMS_TO_TICKS(ota_update_in_progress() ? 1000 : 5000));
    }
}
#endif

/**
 * @brief Watchdog task to monitor system health
 */
static void watchdog_task(void *pvParameters)
{
    while (1) {
        /* Log heap status periodically (debug level - not shown by default) */
        ESP_LOGD(TAG, "Free heap: %lu bytes, minimum: %lu bytes",
                 esp_get_free_heap_size(),
                 esp_get_minimum_free_heap_size());
        
        vTaskDelay(pdMS_TO_TICKS(60000)); /* Every minute */
    }
}

void app_main(void)
{
    /* Initialize log buffer first to capture all logs */
    log_buffer_init(LOG_BUFFER_SIZE);

    /* Recover log history from the previous boot (persisted to flash) and
     * seed it into the fresh RAM ring buffer, then start persisting again */
    {
        static char recovered[LOG_BUFFER_SIZE];
        size_t recovered_len = 0;
        if (log_persist_init(recovered, sizeof(recovered), &recovered_len) == ESP_OK &&
            recovered_len > 0) {
            static const char header[] = "\n===== Recovered log from previous boot =====\n";
            static const char footer[] = "\n===== End of previous boot log =====\n\n";
            log_buffer_seed(header, sizeof(header) - 1);
            log_buffer_seed(recovered, recovered_len);
            log_buffer_seed(footer, sizeof(footer) - 1);
        }
        esp_register_shutdown_handler(log_persist_flush);
        log_persist_start_periodic_flush(300); /* every 5 minutes */
    }

    /* Set default runtime log level to INFO (compile-time is DEBUG to allow switching) */
    esp_log_level_set("*", ESP_LOG_INFO);
    
    /* Quiet down noisy ESP-IDF components - set to WARN level
       This reduces startup spam while keeping important messages */
    esp_log_level_set("wifi", ESP_LOG_WARN);
    esp_log_level_set("wifi_init", ESP_LOG_WARN);
    esp_log_level_set("esp_netif_handlers", ESP_LOG_WARN);
    esp_log_level_set("esp_netif_lwip", ESP_LOG_WARN);
    esp_log_level_set("esp-tls", ESP_LOG_WARN);
    esp_log_level_set("esp-tls-mbedtls", ESP_LOG_WARN);
    esp_log_level_set("esp_https_ota", ESP_LOG_WARN);
    esp_log_level_set("HTTP_CLIENT", ESP_LOG_WARN);
    esp_log_level_set("esp-x509-crt-bundle", ESP_LOG_WARN);
    /* HTTP server internals - extremely verbose, rarely useful */
    esp_log_level_set("httpd_parse", ESP_LOG_WARN);
    esp_log_level_set("httpd_txrx", ESP_LOG_WARN);
    esp_log_level_set("httpd_uri", ESP_LOG_WARN);
    esp_log_level_set("httpd_sess", ESP_LOG_WARN);
    esp_log_level_set("httpd", ESP_LOG_WARN);
    /* Ethernet/network spam */
    esp_log_level_set("esp.emac", ESP_LOG_WARN);
    esp_log_level_set("event", ESP_LOG_WARN);
    
    ESP_LOGI(TAG, "=================================");
    ESP_LOGI(TAG, "Thermux - Temperature Monitor");
    ESP_LOGI(TAG, "Version: %s", APP_VERSION);
    ESP_LOGI(TAG, "=================================");

    /* Initialize NVS */
    esp_err_t ret = nvs_flash_init();
    if (ret == ESP_ERR_NVS_NO_FREE_PAGES || ret == ESP_ERR_NVS_NEW_VERSION_FOUND) {
        ESP_ERROR_CHECK(nvs_flash_erase());
        ret = nvs_flash_init();
    }
    ESP_ERROR_CHECK(ret);

    /* Initialize event loop */
    ESP_ERROR_CHECK(esp_event_loop_create_default());
    
    /* Create network event group */
    network_event_group = xEventGroupCreate();
    
    /* Register IP event handler */
    ESP_ERROR_CHECK(esp_event_handler_register(IP_EVENT, ESP_EVENT_ANY_ID, 
                                                &network_event_handler, NULL));

    /* Initialize TCP/IP stack */
    ESP_ERROR_CHECK(esp_netif_init());

    /* Initialize NVS storage for our app data */
    ESP_ERROR_CHECK(nvs_storage_init());

    /* Load sensor settings from NVS (or use defaults) */
    {
        uint32_t read_ms, publish_ms;
        uint8_t resolution;
        if (nvs_storage_load_sensor_settings(&read_ms, &publish_ms, &resolution) == ESP_OK) {
            s_read_interval_ms = read_ms;
            s_publish_interval_ms = publish_ms;
            ESP_LOGD(TAG, "Loaded sensor settings: read=%lums, publish=%lums, resolution=%d",
                     read_ms, publish_ms, resolution);
            /* Resolution will be applied after onewire_temp_init */
        } else {
            ESP_LOGD(TAG, "Using default sensor settings");
        }
    }

    /* Initialize 1-Wire bus and discover sensors */
    ESP_ERROR_CHECK(onewire_temp_init(CONFIG_ONEWIRE_GPIO));

    /* Apply saved resolution setting */
    {
        uint32_t read_ms, publish_ms;
        uint8_t resolution;
        if (nvs_storage_load_sensor_settings(&read_ms, &publish_ms, &resolution) == ESP_OK) {
            if (resolution >= 9 && resolution <= 12) {
                onewire_temp_set_resolution(resolution);
            }
        }
    }
    
    /* Initialize sensor manager */
    ESP_ERROR_CHECK(sensor_manager_init());

#if CONFIG_USE_ETHERNET
    /* Initialize Ethernet (primary connection for POE) */
    ESP_ERROR_CHECK(ethernet_manager_init());
    ethernet_manager_start();
#endif

#if CONFIG_USE_WIFI_FALLBACK
    /* Initialize WiFi as fallback */
    ESP_ERROR_CHECK(wifi_manager_init());
    
    #if !CONFIG_USE_ETHERNET
    /* If Ethernet is disabled, start WiFi immediately */
    wifi_manager_start();
    #endif
#endif

    /* Wait for network connection. Bounded so a freshly-OTA'd image that
       breaks networking triggers a rollback instead of hanging forever in
       the PENDING_VERIFY state (where it would never be marked good). */
    ESP_LOGD(TAG, "Waiting for network connection...");
    EventBits_t net_bits = xEventGroupWaitBits(
        network_event_group, NETWORK_CONNECTED_BIT, pdFALSE, pdTRUE,
        pdMS_TO_TICKS(CONFIG_OTA_HEALTHCHECK_TIMEOUT_S * 1000));

    if (net_bits & NETWORK_CONNECTED_BIT) {
        ESP_LOGI(TAG, "Network connected!");
        /* Health check passed: keep this firmware. */
        ota_confirm_or_rollback(true);
    } else {
        ESP_LOGE(TAG, "No network after %d s", CONFIG_OTA_HEALTHCHECK_TIMEOUT_S);
        /* If this is a pending OTA image, a missing network means the update
           is bad: roll back to the previous slot (does not return). On a
           normal boot this is a no-op and we keep waiting below. */
        ota_confirm_or_rollback(false);
        ESP_LOGW(TAG, "Continuing to wait for network...");
        xEventGroupWaitBits(network_event_group, NETWORK_CONNECTED_BIT,
                            pdFALSE, pdTRUE, portMAX_DELAY);
        ESP_LOGI(TAG, "Network connected!");
    }

    /* Start SNTP so we can report a wall-clock "Last Boot" time to HA */
    time_sync_init();

    /* Initialize mDNS */
    init_mdns();

    /* Initialize MQTT client */
    ESP_ERROR_CHECK(mqtt_ha_init());

    /* Start web server */
    ESP_ERROR_CHECK(web_server_start());
    ESP_LOGD(TAG, "Web server started on port %d", CONFIG_WEB_SERVER_PORT);

    /* Start the Modbus TCP server if enabled (failure is not fatal) */
    modbus_server_init();
    bacnet_server_init();

#if CONFIG_OTA_ENABLED
    /* Initialize OTA updater */
    ESP_ERROR_CHECK(ota_updater_init());
#endif

    /* Create application tasks */
    xTaskCreate(temperature_task, "temp_task", 4096, NULL, 5, NULL);
    xTaskCreate(mqtt_publish_task, "mqtt_pub_task", 4096, NULL, 4, NULL);
    xTaskCreate(watchdog_task, "watchdog_task", 2048, NULL, 1, NULL);
    
#if CONFIG_OTA_ENABLED
    xTaskCreate(ota_check_task, "ota_task", 8192, NULL, 2, NULL);
    xTaskCreate(ota_status_publish_task, "ota_status_task", 4096, NULL, 2, NULL);
#endif

    ESP_LOGI(TAG, "Application started successfully!");
}

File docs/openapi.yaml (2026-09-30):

openapi: 3.1.0
info:
  title: Thermux API
  description: |
    REST API for the Thermux multi-sensor temperature monitoring system.
    
    Thermux is an ESP32-based temperature monitoring system that supports up to 100 DS18B20 sensors
    (20 by default) with Home Assistant integration via MQTT auto-discovery and an optional
    read-only Modbus TCP server.
    
    ## Authentication
    
    When authentication is enabled, most API endpoints require authentication via one of the following methods:
    
    - **Session Cookie**: Obtain by calling `POST /api/auth/login` with credentials. The session cookie
      is automatically included in subsequent requests.
    - **API Key**: Include the `X-API-Key` header with your API key for stateless API access.
    
    Endpoints under `/api/auth/*` do not require authentication.
  version: 1.0.0
  license:
    name: MIT
    url: https://github.com/sslivins/thermux/blob/main/LICENSE
  contact:
    name: Thermux Project
    url: https://github.com/sslivins/thermux

servers:
  - url: http://thermux.local
    description: mDNS hostname (default)
  - url: http://{device_ip}
    description: Device IP address
    variables:
      device_ip:
        default: 192.168.1.100

tags:
  - name: Status
    description: Device status and system information
  - name: Sensors
    description: Temperature sensor management
  - name: Configuration
    description: Device configuration endpoints
  - name: Modbus
    description: Modbus TCP server settings and sensor channels
  - name: Authentication
    description: Login, logout, and session management
  - name: OTA
    description: Over-the-air firmware updates
  - name: Logs
    description: System log management
  - name: System
    description: System control operations

paths:
  /api/status:
    get:
      tags:
        - Status
      summary: Get device status
      description: Returns system information including version, uptime, memory, and network status.
      operationId: getStatus
      security:
        - sessionCookie: []
        - apiKey: []
      responses:
        '200':
          description: Device status information
          content:
            application/json:
              schema:
                $ref: '#/components/schemas/DeviceStatus'
        '401':
          $ref: '#/components/responses/Unauthorized'

  /api/sensors:
    get:
      tags:
        - Sensors
      summary: Get all sensors
      description: Returns all discovered temperature sensors with current readings.
      operationId: getSensors
      security:
        - sessionCookie: []
        - apiKey: []
      responses:
        '200':
          description: List of temperature sensors
          content:
            application/json:
              schema:
                type: array
                items:
                  $ref: '#/components/schemas/Sensor'
              example:
                - address: "28FF1234567890AB"
                  temperature: 22.5
                  valid: true
                  friendly_name: "Living Room"
                - address: "28FF0987654321CD"
                  temperature: 18.3
                  valid: true
                  friendly_name: null
        '401':
          $ref: '#/components/responses/Unauthorized'

  /api/sensors/rescan:
    post:
      tags:
        - Sensors
      summary: Rescan for sensors
      description: Triggers a new 1-Wire bus scan to discover sensors.
      operationId: rescanSensors
      security:
        - sessionCookie: []
        - apiKey: []
      responses:
        '200':
          description: Rescan result
          content:
            application/json:
              schema:
                type: object
                properties:
                  success:
                    type: boolean
                    description: Whether the rescan was successful
                  sensor_count:
                    type: integer
                    description: Number of sensors discovered
                example:
                  success: true
                  sensor_count: 5
        '401':
          $ref: '#/components/responses/Unauthorized'

  /api/sensors/error-stats/reset:
    post:
      tags:
        - Sensors
      summary: Reset all error statistics
      description: |
        Resets the 1-Wire bus error counters (total reads and failed reads) to zero,
        as well as all per-sensor error statistics.
      operationId: resetErrorStats
      security:
        - sessionCookie: []
        - apiKey: []
      responses:
        '200':
          description: Statistics reset successfully
          content:
            application/json:
              schema:
                type: object
                properties:
                  success:
                    type: boolean
                example:
                  success: true
        '401':
          $ref: '#/components/responses/Unauthorized'
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

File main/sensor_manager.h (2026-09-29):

/**
 * @file sensor_manager.h
 * @brief Sensor registry and management with friendly names
 */

#ifndef SENSOR_MANAGER_H
#define SENSOR_MANAGER_H

#include "esp_err.h"
#include "onewire_temp.h"
#include <stdbool.h>

#define MAX_FRIENDLY_NAME_LEN 32

/**
 * @brief Managed sensor with friendly name
 */
typedef struct {
    onewire_sensor_t hw_sensor;               /**< Hardware sensor data */
    char friendly_name[MAX_FRIENDLY_NAME_LEN]; /**< User-assigned friendly name */
    bool has_friendly_name;                    /**< True if friendly name is set */
    char address_str[17];                      /**< Address as hex string */
    int64_t last_attempt_time;                 /**< Uptime (ms) of the last read attempt, 0 if never */
} managed_sensor_t;

/**
 * @brief Outcome of the most recent read cycle
 */
typedef enum {
    SENSOR_CYCLE_OK = 0,          /**< Every sensor read successfully */
    SENSOR_CYCLE_PARTIAL = 1,     /**< Some sensors failed */
    SENSOR_CYCLE_FAILED = 2,      /**< No sensor read successfully (bus failure, lock timeout, ...) */
    SENSOR_CYCLE_NO_SENSORS = 3,  /**< No sensors discovered */
} sensor_cycle_result_t;

/**
 * @brief Read-cycle bookkeeping, updated after every scheduled read attempt
 */
typedef struct {
    uint32_t cycle_count;              /**< Increments after every attempted cycle (wraps) */
    sensor_cycle_result_t last_result; /**< Result of the most recent cycle */
    int64_t last_cycle_time;           /**< Uptime (ms) when the last cycle finished, 0 if none */
} sensor_cycle_info_t;

/**
 * @brief Initialize sensor manager and discover sensors
 */
esp_err_t sensor_manager_init(void);

/**
 * @brief Re-scan for sensors (hot-plug support)
 *
 * Serialized with read cycles, so a read never pairs the old registry with
 * the newly scanned device order.
 */
esp_err_t sensor_manager_rescan(void);

/**
 * @brief Read temperatures from all sensors
 */
esp_err_t sensor_manager_read_all(void);

/**
 * @brief Publish all sensor readings via MQTT
 */
esp_err_t sensor_manager_publish_all(void);

/**
 * @brief Copy the current sensor registry
 *
 * Returns a heap-allocated copy that the caller owns and must free(). The
 * copy is consistent (taken under the registry lock) and stays valid across
 * rescans.
 *
 * @param count Output: number of sensors in the copy
 * @return Array of @p count sensors, or NULL if there are none or allocation failed
 */
managed_sensor_t *sensor_manager_snapshot(int *count);

/**
 * @brief Get read-cycle bookkeeping
 */
void sensor_manager_get_cycle_info(sensor_cycle_info_t *out);

/**
 * @brief Set friendly name for a sensor
 * @param address_str Sensor address as hex string
 * @param friendly_name Friendly name to set
 */
esp_err_t sensor_manager_set_friendly_name(const char *address_str, const char *friendly_name);

/**
 * @brief Copy a single sensor by address string
 * @param address_str Sensor address as hex string
 * @param out Output copy of the sensor
 * @return ESP_OK, or ESP_ERR_NOT_FOUND if no sensor has that address
 */
esp_err_t sensor_manager_get_sensor(const char *address_str, managed_sensor_t *out);

/**
 * @brief Get number of sensors
 */
int sensor_manager_get_count(void);

/**
 * @brief Reset error stats for all sensors
 */
void sensor_manager_reset_all_error_stats(void);

/**
 * @brief Reset error stats for a specific sensor
 * @param address_str Sensor address as hex string
 * @return ESP_OK on success, ESP_ERR_NOT_FOUND if sensor not found
 */
esp_err_t sensor_manager_reset_sensor_error_stats(const char *address_str);

#endif /* SENSOR_MANAGER_H */

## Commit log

2026-01-29 improved settings page, fixed some issues with friendly names
    [main.c]
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2026-01-30 Fix disabled button hover effects
    - Add pointer-events: none to .btn:disabled to prevent mouse interactions
    - Simplify hover selectors (remove :not(:disabled) since pointer-events handles it)
    - Affects Install Update and Upload Firmware buttons when disabled
    [main.c]
2026-01-31 finally fixed firmware update check, removed custom minify and use one from python instead (#13)
    [html_minifier.py, main.c]
2026-01-31 Fix firmware progress (#16)
    * firmware progress is much better now for both manual and github updates
    * fixed mqtt connected status color
    [main.c]
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2026-02-12 Add per-sensor error stats to OpenAPI Sensor schema
    [openapi.yaml]
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2026-02-13 Add sort by error rate option, bump to 2.4.0 (#29)
    - Add 'Error Rate' option to sensor sort dropdown
    - Sorts sensors by failed_reads/total_reads (highest first)
    - Useful for identifying problematic sensors at a glance
    [main.c]
2026-02-14 Redesign firmware update UI with Cloud/File tabs
    - Replace disorganized layout with two clear source tabs: Cloud and Local File
    - Single 'Install Update' button that works for whichever source is active
    - Cloud tab: check for updates, shows latest version and availability
    - File tab: file picker for manual .bin uploads (downgrades, custom builds)
    - Shared progress bar and status message at bottom, only visible during install
    - Tabs lock during active update to prevent confusion
    - Renamed GitHub references to generic 'Cloud' for future flexibility
    - Bump version to 2.6.0
    [main.c]
2026-08-03 Fix friendly-name NVS key collision (drop unique serial bytes) (#35)
    The NVS key for a sensor's friendly name was built from ROM bytes [4..7]
    (top 3 serial bytes + the derived CRC), dropping unique serial bytes
    [1..3]. Two DS18B20 sensors sharing bytes [4..7] collided to the same
    key, so naming one sensor aliased/overwrote another.
    Key now uses the full unique 48-bit serial (bytes [1..6]) -> collision
    free. "s_" + 12 hex = 14 chars, within the 15-char NVS key limit.
    Existing devices migrate transparently: nvs_storage_load_sensor_name
    falls back to the legacy key (bytes [4..7]), and on a hit re-keys the
    value to the new format and erases the legacy entry (one-time, per
    connected sensor, on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
2026-08-03 Bump version to 2.7.1 for friendly-name NVS key collision fix (#36)
    [main.c]
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2026-08-03 fix(ota): grow GitHub API response buffer dynamically (#38)
    The OTA update check read GitHub's /releases/latest response into a
    fixed 4096-byte buffer. The payload is now ~8KB (multiple release
    assets plus author/uploader objects and release notes), so the buffer
    filled and the JSON was truncated, causing 'Failed to parse JSON
    response'. This broke both the web UI update check and the new Home
    Assistant firmware update entity (latest_version reported 'unknown').
    Replace the fixed buffer with a dynamically growing one (initial 8KB,
    doubling up to a 64KB safety cap) so the full response is captured and
    parsed. Also bump APP_VERSION to 2.8.1.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
    [main.c]
2026-08-03 fix(ota): select the app binary, not bootloader, from release assets (#40)
    The OTA update check picked the first release asset whose name merely
    contained '.bin'. thermux releases ship three such assets
    (bootloader.bin, partition-table.bin, thermux.bin), so it selected
    bootloader.bin. Flashing the bootloader image into the app OTA slot
    corrupted the slot and caused the bootloader to fall back to the
    factory image (old 'ESP32 PoE Temperature Monitor' v1.1.0) on reboot.
    Now select the exact app asset '<repo>.bin' (e.g. thermux.bin),
    explicitly skipping bootloader.bin and partition-table.bin, with a
    safe fallback to any other .bin. Abort the update task if no download
    URL was resolved. Bump AP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
    [main.c]
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2026-08-11 Improve bus health diagnostics (#43)
    Add rolling error health, uptime, last-success visibility, and matching Home Assistant and Web UI diagnostics.
    [onewire_temp.c, openapi.yaml]
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2026-08-13 Add OTA rollback safety net + Last Boot timestamp (#46)
    Enable bootloader app rollback so a bad OTA can recover on its own, and
    report a wall-clock "Last Boot" timestamp to Home Assistant instead of raw
    uptime seconds.
    Rollback safety:
    - Enable CONFIG_BOOTLOADER_APP_ROLLBACK_ENABLE. A freshly flashed image now
    boots in PENDING_VERIFY and must confirm itself healthy or the bootloader
    reverts to the previous known-good slot.
    - app_main waits up to CONFIG_OTA_HEALTHCHECK_TIMEOUT_S (default 60s) for the
    network. If it comes up, mark the app valid; if not, invalidate and reboot
    into the previous slot. Gated on the network (Ethernet), not MQTT, so a
    broker outage cannot cause a false ro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
    [main.c]
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2026-08-20 Expose raw scratchpad diagnostic bytes for clone detection (#57)
    Adds count_remain/count_per_c/genuine_check_ok fields to onewire_sensor_t
    and /api/sensors so the actual scratchpad values used by the genuineness
    heuristic can be inspected remotely (no serial access needed), since some
    clone families forge the ROM pattern too and a plain pass/fail bool isn't
    enough to diagnose why a known-clone sensor isn't being flagged.
    [onewire_temp.c]
2026-08-20 Fix network status UI nits on settings page (#58)
    - Show 'Current: Disconnected' for WiFi SSID when not connected,
    instead of showing the configured SSID even when offline.
    - Decouple the IP address display from the specific interface: show
    a single active IP (whichever interface is actually connected)
    independent of the Ethernet/WiFi connection badges, rather than
    showing per-interface IPs awkwardly next to each badge.
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2026-08-20 Fix conversion-time clone check to work at any resolution (#61)
    Previously the 12-bit conversion-time side-channel test only ran when
    the device's globally configured resolution was 12-bit, so it was
    silently skipped on devices running at lower resolutions (e.g. 11-bit)
    - exactly the case that surfaced this in testing.
    Now the check temporarily writes the scratchpad's config byte to force
    12-bit mode for the duration of the timing measurement (not persisted
    to EEPROM), then restores the original TH/TL/config bytes, so the
    signal works regardless of the sensor's normal configured resolution.
    [onewire_temp.c]
2026-08-20 Redesign firmware update section as index-card style panels (#62)
    Cloud and Local File options now render as a single bordered card group with a heading-style tab strip, rather than separate buttons above a floating content box.
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2026-08-20 Refine clone/genuine sensor badges (#64)
    - Genuine badge changed from checkmark to shield icon (avoids implying an ADI/Maxim trademark endorsement).
    - Shortened both badge tooltips to a brief one-liner.
    - Badges now also respond to tap/click (shows a toast), since title tooltips don't work on touch devices.
2026-08-20 Replace always-visible name textbox with pencil-edit control (#65)
    - Sensor name now shows as plain text with a small pencil icon; clicking it reveals an inline input + save/cancel buttons.
    - Moved the clone/genuine badge to the top-right corner of the sensor card (absolute positioned) instead of inline next to the name.
2026-08-20 Save sensor name on blur/Enter, drop explicit save/cancel buttons (#66)
    * Save sensor name on blur/Enter instead of explicit buttons
    Removes the save/cancel buttons from the inline name edit control.
    Enter or clicking away now saves the name; Escape cancels the edit
    and reverts to the previous value - matches the common inline-edit
    pattern used by Trello/Notion-style UIs.
    * Add cancel button back for touch devices (no Escape key on mobile)
    iOS/mobile keyboards have no Escape key, so add a small X cancel icon
    next to the input, visible only while editing. Uses onmousedown +
    preventDefault so it fires before the input's b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
2026-08-20 Fix cancel button vertical alignment in inline name edit (#67)
    Remove leftover margin-top from .sensor-name-input (a holdover from
    the old always-visible textbox layout) that pushed the input down
    relative to the cancel button in the flex row. Input now uses
    flex:1 to fill the row alongside the cancel button.
2026-08-20 Fix cancel button overlapping clone/genuine badge (#68)
    The .sensor-name row extended full width, so the cancel (X) button
    sat directly under the absolutely-positioned clone/genuine badge in
    the card's top-right corner. Taps intended for X were landing on the
    badge instead, which then let the input's blur handler save the name
    instead of cancelling. Added padding-right to .sensor-name to keep
    the row clear of the badge.
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2026-08-20 Fix infinite retry loop in onewire_temp_scan on repeated bus errors (#74)
    If onewire_device_iter_get_next() returns a non-NOT_FOUND error
    repeatedly (e.g. no sensor wired, marginal/noisy 1-wire bus), the
    scan loop retried immediately with no delay and no limit, spinning
    forever and flooding the log. Cap consecutive errors at 5 and add a
    short delay between retries; after the cap is hit, treat it like no
    devices were found and abort the scan.
    [onewire_temp.c]
2026-08-21 Bump version to 2.10.13 (#75)
    Includes the onewire_temp_scan infinite retry loop fix.
    [main.c]
2026-08-21 Update partition layout to reclaim dead factory partition
    Brand-new devices now get the same layout that existing field devices
    were migrated to entirely over-the-air: no factory partition, OTA_0/OTA_1
    grown from 1.2MB to 1.875MB each. See issue #48 for the full migration
    design and validation history (dry runs on a spare device, then applied
    to 192.168.10.127).
    [partitions.csv]
2026-08-21 Bump APP_VERSION to 3.0.0 (#76)
    Marks the new partition layout (factory partition reclaimed, OTA_0/OTA_1
    grown to 1.875MB each) as a major version milestone. See issue #48 and
    FLASHING.md for details.
    [main.c]
2026-08-21 Add backup/restore for sensor names and settings (#77)
    Adds GET /api/backup and POST /api/backup/restore endpoints plus a new
    "Backup / Restore" section in the settings UI, so sensor friendly-name
    mappings survive a device re-flash without manual re-entry.
    - Sensor names and read/publish interval + resolution are always included.
    - MQTT broker settings, WiFi credentials, and login/API-key are optional,
    selected via checkboxes in a backup modal (MQTT on by default, WiFi and
    auth off by default since they're higher-value secrets).
    - Backup is plain JSON (not encrypted) with the tradeoffs explained in the
    UI - only include credential sections if the downloaded file will be
    stored secur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
    [onewire_temp.c]
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2026-08-22 Bump APP_VERSION to 3.1.0
    v3.0.0 was tagged/released before the backup/restore feature (#77),
    config.html test coverage (#78 test infra), and the HA entity_id fix
    (#79) merged, so the published v3.0.0 release doesn't actually contain
    them. Bumping to 3.1.0 so the next Create Release run picks up a fresh
    tag with all of main's current changes.
    [main.c]
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2026-08-22 Add settings page quick-nav shortcuts; mark prerelease tags as prerelease; bump to 3.3.0-beta.1 (#86)
    - Add a sticky shortcut bar at the top of config.html linking to each
    settings panel (Network, MQTT, Sensors, Firmware, Logs, Security,
    Backup, System) via in-page anchors.
    - Mark GitHub Releases as prerelease in create-release-tag.yml whenever
    APP_VERSION contains a SemVer pre-release suffix (e.g. -beta.1), so
    betas don't show up as 'Latest' release.
    - Bump APP_VERSION to 3.3.0-beta.1 to test the new feature via the OTA
    beta channel.
    [main.c]
2026-08-22 Fix OTA prerelease check failing with unknown version (#87)
    Reduce GITHUB_API_URL_LIST per_page from 5 to 3 so the releases-list
    JSON response stays well under the buffer-growth failure point seen on
    heap-constrained devices (39.7KB response required growing to the 64KB
    cap, which failed under real-world heap fragmentation, leaving
    latest_version empty and the UI showing 'unknown'). A per_page=3
    response (~24KB) fits within the 32KB growth tier.
    Bump APP_VERSION to 3.3.0-beta.2 so this fix is OTA-testable.
    [main.c]
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2026-08-22 Serialize 1-Wire bus access between rescan and periodic reads (#90)
    The rescan handler (POST /api/sensors/rescan) and the background
    temperature_task both talked directly to the shared 1-Wire bus handle
    with no coordination. Since 1-Wire timing is precise (reset pulses,
    presence detection, bit slots), an in-flight read cycle interleaving
    with a device search on the same wire could corrupt the search and
    silently drop sensors from the scan results - matching the reported
    'rescan sometimes misses sensors' symptom.
    Add a mutex around the only two functions that touch the bus
    (onewire_temp_scan, onewire_temp_read_all) with a bounded 5s timeout,
    so one op waits for the other to finish rather tha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
    [onewire_temp.c]
2026-08-22 Bump APP_VERSION to 3.3.0 (#92)
    Promotes the 3.3.0 beta line to an official release: settings page
    quick-nav shortcuts, OTA prerelease-check buffer-size fix, 5s minimum
    sensor read interval, and the 1-Wire bus mutex fix for rescan vs.
    periodic-read contention.
    [main.c]
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2026-08-25 Fix 32-bit tick overflow in OTA check interval (#99)
    * Bump version to 3.3.4
    * Fix 32-bit tick overflow in OTA check interval
    CONFIG_OTA_CHECK_INTERVAL_HOURS * 3600 * 1000 passed to pdMS_TO_TICKS()
    overflowed a 32-bit int at the default 24h interval, wrapping the
    intended 24-hour delay down to ~8.4 minutes. This caused the OTA
    checker to re-run every ~8 minutes instead of daily, producing the
    observed flip-flopping between up-to-date/update-available in HA.
    Compute the interval in whole seconds first, then multiply by
    pdMS_TO_TICKS(1000) (ticks-per-second), keeping intermediate values
    well under 32-bit overflow even at the max allowed 168h interval.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
    [main.c]
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2026-08-29 Persist log history to flash across reboots (#104)
    Uses the previously-declared-but-unused 64KB 'storage' partition
    to survive reboots/crashes. Writes 2 rotating 16KB slots (32KB of
    the partition, leaving the rest unused) with magic/sequence/CRC32
    headers for wear-leveling and corruption detection. Flushes every
    5 minutes and before any planned esp_restart() via a registered
    shutdown handler. Recovered log is seeded into the RAM ring buffer
    at boot so /api/logs shows history across the reboot boundary.
    [main.c]
2026-08-30 Add MQTT reconnecting status + error surfacing to web UI (#105)
    The MQTT status badge previously only showed a binary Connected/Online
    vs Disconnected/Offline. Since esp-mqtt auto-reconnects forever, a device
    stuck retrying (e.g. wrong/unreachable broker) looked identical to a hard
    failure, with no hint as to why.
    Firmware:
    - Track connecting state + decode the last connection error
    (DNS resolve failure, network errno, broker-refused reasons) in
    mqtt_client_ha, guarded by a mutex for cross-task reads.
    - Expose mqtt_connecting, mqtt_last_error and mqtt_last_error_age_sec
    via /api/status.
    UI:
    - Home page (index.html): amber pulsing "Reconnecting..." state with the
    error as a tooltip,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
    [main.c]
2026-08-30 MQTT: auto-apply config on save, beta labelling, config-form UX (#106)
    * MQTT: auto-apply config on save, beta labelling, and config-form UX
    Follow-ups from testing the new MQTT status badge on-device.
    Auto-reconnect on config change:
    - Saving MQTT settings only wrote NVS; the running esp-mqtt client kept
    using the old in-memory broker/credentials and auto-retried them forever,
    so a corrected config never took effect until the manual "Reconnect"
    button (which re-inits from NVS). Now POST /api/config/mqtt applies the
    new settings live. Added mqtt_ha_reconnect() (tears down + rebuilds the
    client from NVS, sets the "connecting" state immediately) and routed both
    the save handler a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
    [main.c]
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2026-09-29 feat: thread-safe sensor registry and support for up to 100 sensors (#108) (#110)
    Groundwork for the Modbus TCP server (#108).
    - sensor_manager: split into cycle lock (bus I/O) and data lock (short
    copies); rescan builds a new registry and swaps it atomically.
    Readers get heap snapshots instead of a raw pointer into shared state.
    - Cycle info (counter, last result, time) and per-sensor last attempt
    time for status/staleness reporting.
    - Whole-bus read failures now mark sensors invalid instead of leaving
    stale values looking fresh.
    - onewire_temp: cache genuineness checks by ROM so rescans don't redo
    the ~0.6 s check per sensor; free old device handles on rescan (leak);
    check cal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
    [onewire_temp.c, sensor_manager.h]
2026-09-29 feat: read-only Modbus TCP server with fixed 100-slot register map (#108) (#111)
    Adds an opt-in (disabled by default) Modbus TCP server that exposes sensor
    temperatures, status, reading age and ROM IDs as input registers (FC04 only).
    The register map is fixed at 100 slots regardless of CONFIG_MAX_SENSORS, and
    sensors keep a stable slot (persisted in NVS) across rescans and reboots.
    - modbus_map: portable, host-tested register map, status rules, slot table
    and versioned CRC-protected slot blob
    - modbus_server: esp-modbus 2.1.3 lifecycle, notification drain task, NVS
    config, _mbap._tcp mDNS advertisement, safe config apply with rollback
    - GET/POST /api/modbus, modbus_slot in /api/sensors,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
    [main.c, modbus_map.h]
2026-09-29 fix: stop a foreign Modbus unit ID from wedging the server (#108) (#112)
    esp-modbus 2.1.3 silently drops a TCP frame whose unit ID does not match,
    without releasing the transaction resource it took for that frame. Every
    later request then goes unanswered until reboot; found on a device with a
    single read addressed to unit ID 2.
    Turn off esp-modbus's own unit ID filter (FMB_TCP_UID_ENABLED) so it
    processes every frame, and filter in a wrapper around the FC04 handler
    instead, reading the unit ID from the MBAP header byte before the PDU.
    A foreign unit ID now gets exception 0x0B (gateway target failed to
    respond). Unit IDs 0 and the configured ID are accepted; esp-modbus 2.1.3
    drops IDs above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
    [modbus_map.h]
2026-09-29 feat: Modbus slot management UI, backup/restore and register map docs (#108) (#113)
    - Settings page: "Sensor slots" table to move sensors between Modbus
    slots (swaps when the target is taken) and release slots of sensors
    that are no longer connected.
    - New GET/POST /api/modbus/slots. The list is built from the same
    register image Modbus clients read, so the two always agree.
    - Backup schema 2 adds a modbus section (settings + slot table); restore
    applies it after the restart. Schema 1 backups leave Modbus untouched.
    - README: Modbus TCP section with the full register map, status codes,
    consistent-read recipe, unit ID behaviour and client examples.
    - OpenAPI: /api/modbus and /api/mo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
    [modbus_map.h, openapi.yaml]
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2026-09-30 feat: inline pencil editing for Modbus channels, plus a Modbus reader script (#115)
    Channel table: each channel number now has a pencil button that turns it
    into an inline number field with save/cancel icons. Enter saves, Escape
    cancels, and only one row is edited at a time. An invalid number keeps the
    editor open, and saving an unchanged number just closes it. This replaces
    the always-visible number box and Move button on every row. Release is
    still only shown for missing sensors.
    scripts/thermux_modbus.py: a small pymodbus-based reader. Given a host it
    decodes the Thermux register map (device info plus every channel's
    temperature, status, age and ROM ID), using the read-cycle counter to g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
    [thermux_modbus.py]
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2026-09-30 chore: release 3.4.0 (#119)
    Modbus TCP server with stable per-sensor channels, channel management
    UI (inline pencil editing, swap/release), themed confirm dialogs for
    desktop and mobile, and scripts/thermux_modbus.py.
    [main.c]
2026-09-30 fix: Modbus firmware version and refused OTA updates (3.4.1) (#120)
    Modbus registers 1-3 reported 3.3.11 on the 3.4.0 release: they came
    from esp_app_desc, which is `git describe` at build time, and the
    release is built before its tag exists (v3.3.11-11-gad8687d). Use
    APP_VERSION like the rest of the firmware.
    Every OTA check cleared "update available" before contacting GitHub,
    so an Update click during a check (the automatic one 60 s after boot,
    or the daily one) answered "No update available", and a failed check
    hid a known update until the next successful one. A check now builds
    its result in locals and only replaces the published result when it
    succeeds. On the bench, polling /api/ota/s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
    [main.c]
2026-09-30 temp: one-off web login recovery for a single unit (3.4.2) (#121)
    Resets the web login to admin/admin only on a unit that has saved names
    for two specific sensor ROM IDs. To be removed in the next release.
    [main.c]
2026-09-30 feat(login): make repeated failed logins visible; remove 3.4.2 recovery (3.4.3) (#122)
    - Move the login page out of a C string into main/html/login.html,
    embedded gzipped like the other pages, so it can be tested.
    - Hide the error as soon as the user types; every failed attempt shows
    it again with a short shake (a colour flash with reduced motion).
    - Clear and refocus the password after a failure, disable Sign In while
    a request is in flight, and say when the device can't be reached.
    - role=alert so screen readers announce each failure.
    - Remove the one-off login recovery added in 3.4.2.
    [main.c]
2026-10-01 feat: BACnet/IP server (3.5.0) (#124)
    * feat: add BACnet/IP server
    Add a read-only BACnet/IP server alongside Modbus TCP, with Device and Analog Input objects backed by the existing channel table. Wire configuration through NVS, backup/restore, the web API, settings UI, host logic tests, UI tests, documentation, and a BACnet reader script.
    * fix(bacnet): cut RAM use, recover after network changes
    The first BACnet build left ~40 KB free heap; the EMAC then ran out of
    receive buffers and the web server crashed on a NULL cJSON result.
    - Allocate object tables only while the server runs; no per-cycle
    snapshot malloc and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
    [main.c]
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2026-10-01 Fix GitHub update check and download running out of memory (#126)
    On a busy unit (BACnet + MQTT + 10 sensors) the update check failed with
    "Failed to allocate memory for output buffer", and the firmware download
    failed the TLS handshake (PK verify 0x4290, MPI alloc).
    - Update check: stream the GitHub release JSON through a small fixed-size
    scanner (release_scan.c, ~1.2 KB) instead of buffering the whole
    response and parsing it with cJSON. Unit tested against real GitHub
    responses.
    - Download: one streamed GET instead of 64 KB range requests (~20 TLS
    handshakes), 4 KB buffers, heap logged on start/failure.
    - Check and download no longer run at the same time: the boot/daily
    check co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
    [main.c]
